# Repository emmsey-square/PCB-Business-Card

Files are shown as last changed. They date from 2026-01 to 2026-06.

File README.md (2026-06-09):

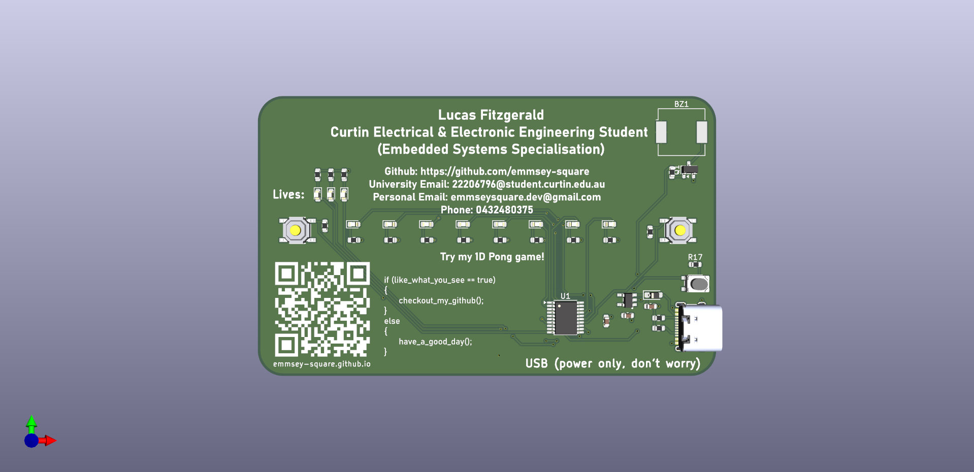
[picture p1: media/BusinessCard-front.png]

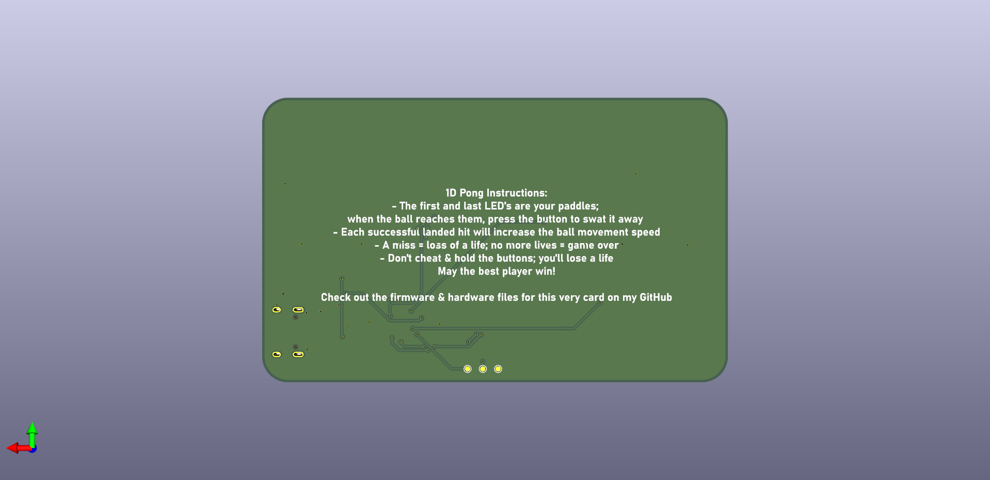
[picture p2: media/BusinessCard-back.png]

#   PCB Business Card- A Business Card to Help Me Stand Out

## Brief 
I've seen online heaps of people in the hobbyist/engineering field design their own business cards/badges to  give out to people, and I wnated to make one of my own to help me stand out among my peers.

My spin on the PCB business card is a simple 1D Pong game; there's a string of LED's between two pushbutton switches, with one LED lighting up at a time and moving along the string in alternating directions. When the LED reaches the end of the string, the player must press the button on that side to 'swat' it away, otherwise they will lose 1 of their 3 lives. Each successful swat increases the speed of the LED movement, until eventually it's impossible to win. Additionally, holding the buttons the whole time (AKA cheating) results in a loss of a life. Losing all lives results in game over. 
## Design Choices 
- Utilising a CH32V003 for my main mcu, as it is a cheap 32-bit RISCV chip with plenty of peripherals and IO for a business card. I have an interest in the RISCV ISA, and there's a huge open source community around this chip mainly thanks to cnlohr and his [ch32fun SDK](https://github.com/cnlohr/ch32fun) 
- USB-C port port mainstream compatibility, although people will be understandably hesitant to plug this into things
- Onboard passive buzzer for sound effects (work in progress)

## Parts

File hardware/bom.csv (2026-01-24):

Id | Designator | Footprint | Quantity | Designation | Supplier and ref
1 | J1 | USB-C_16 | 1 | USB_C_Receptacle
2 | R13,R8,R10,R9,R5,R7,R11,R12,R15,R14,R6 | R_0603_1608Metric | 11 | R
3 | R3,R4 | R_0603_1608Metric | 2 | 5.1k
4 | Q1 | SOT-23 | 1 | BC847
5 | D5,D4,D1,D3,D12,D7,D2,D8,D11,D10,D6 | LED_0603_1608Metric | 11 | LED
6 | U1 | TSSOP-20_4.4x6.5mm_P0.65mm | 1 | CH32V003FxPx
7 | BZ1 | Buzzer_CUI_CPT-9019S-SMT | 1 | Buzzer
8 | R17,R1,R2 | R_0603_1608Metric | 3 | 10k
9 | SW3 | Push_SMD_4.2x3.2mm | 1 | SMD_4.2x3.2mm_h2.5mm
10 | SW2,SW1 | Push_SMD_5.2x5.2mm_h1.9mm | 2 | SMD_5.2x5.2mm_h1.9mm
11 | C3 | C_0603_1608Metric | 1 | 10u
12 | D9 | D_SOD-323_HandSoldering | 1 | 1N5819WS
13 | R16 | R_0603_1608Metric | 1 | R
14 | C1 | C_0603_1608Metric | 1 | 0.1u
15 | U2 | SOT23-5 | 1 | RT9080-3.3
16 | C2 | C_0603_1608Metric | 1 | 1u
17 | TP3 | TestPoint_Pad_D1.0mm | 1 | GND
18 | TP1 | TestPoint_Pad_D1.0mm | 1 | SWIO
19 | TP2 | TestPoint_Pad_D1.0mm | 1 | 3.3V

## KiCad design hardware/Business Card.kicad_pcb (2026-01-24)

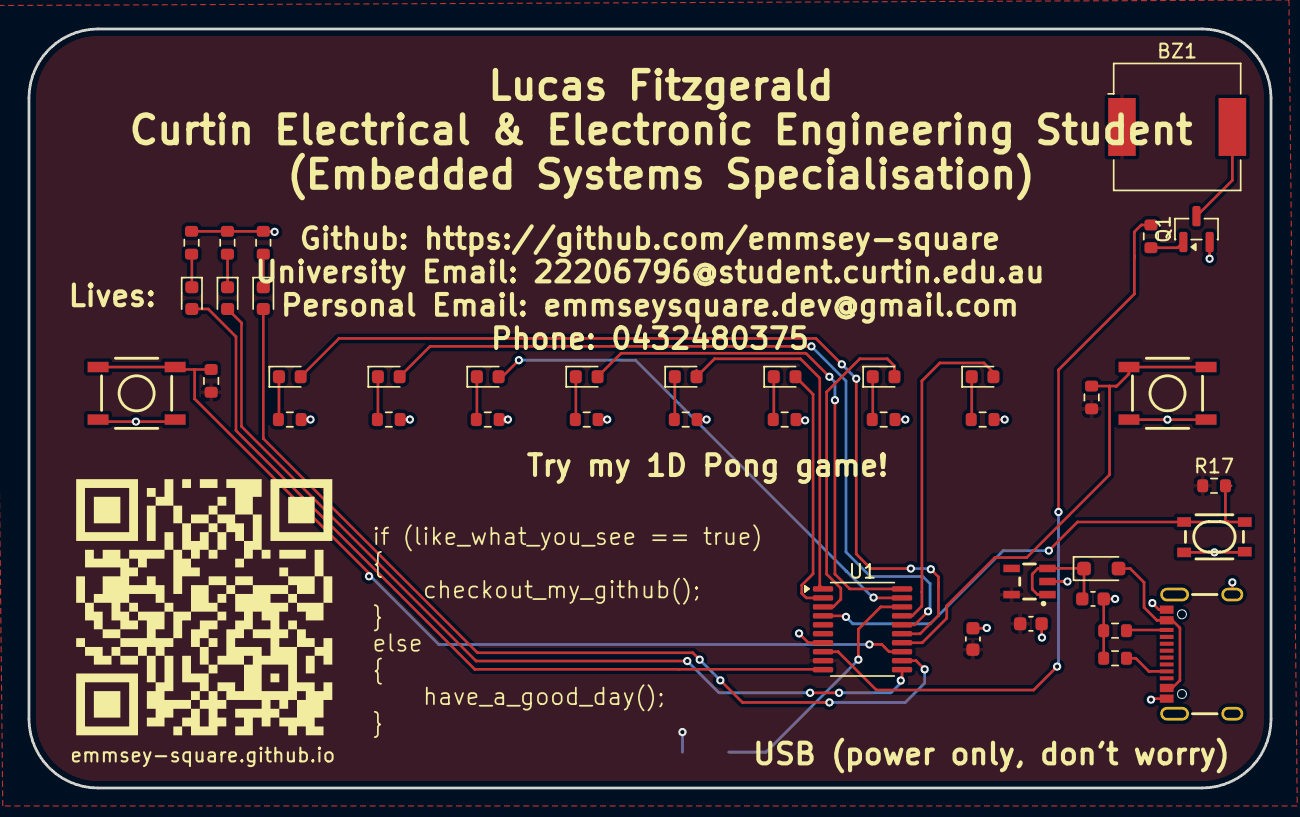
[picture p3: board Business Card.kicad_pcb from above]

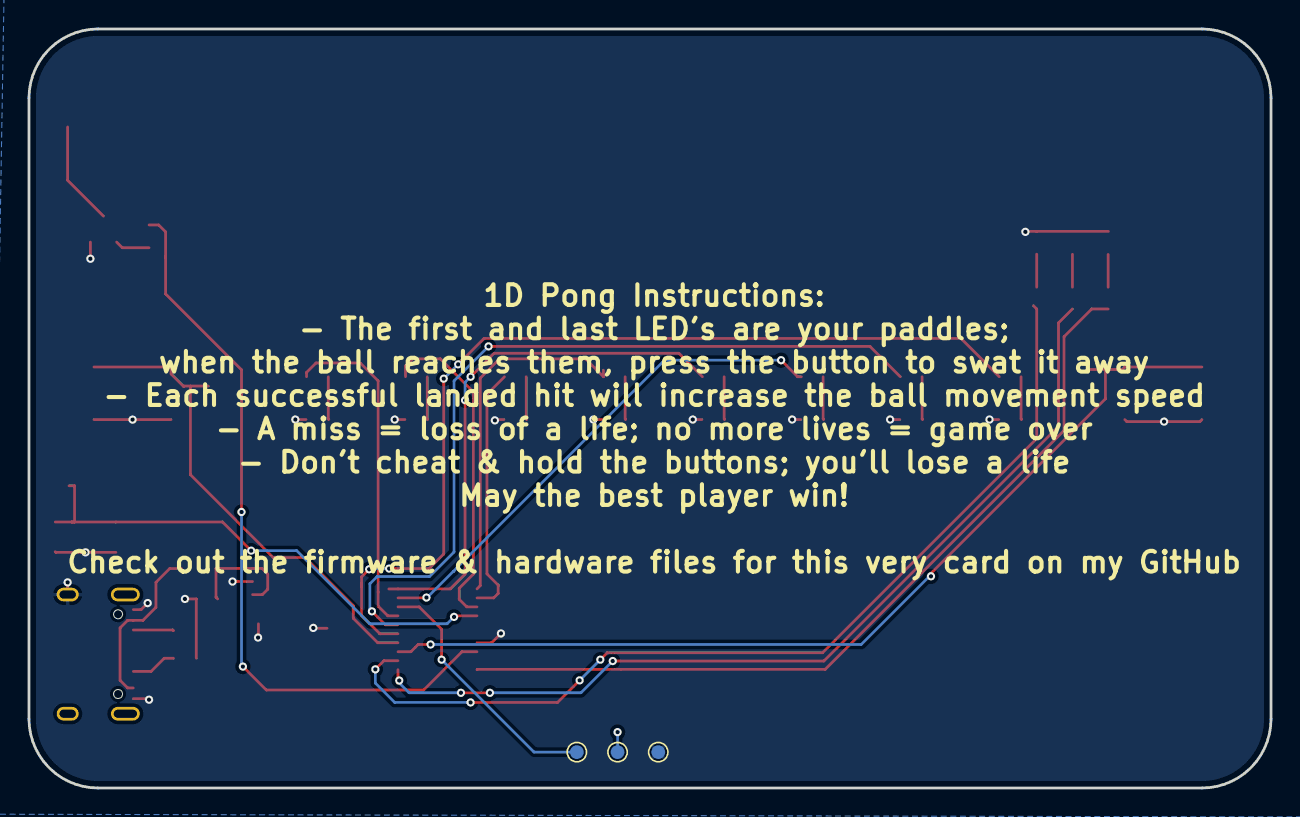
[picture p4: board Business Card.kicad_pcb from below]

Board: 2 copper layers, 90.0 x 55.0 mm, 43 parts (3 on the bottom side), 35 nets.

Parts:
BZ1: Buzzer; Buzzer_CUI_CPT-9019S-SMT
C1: 0.1u; C_0603_1608Metric
C2: 1u; C_0603_1608Metric
C3: 10u; C_0603_1608Metric
D1, D2, D3, D4, D5, D6, D7, D8, D10, D11, D12: LED; LED_0603_1608Metric
D9: 1N5819WS; D_SOD-323_HandSoldering
J1: USB_C_Receptacle; USB-C_16
Q1: BC847; SOT-23
R1, R2, R17: 10k; R_0603_1608Metric
R3, R4: 5.1k; R_0603_1608Metric
R5, R6, R7, R8, R9, R10, R11, R12, R13, R14, R15, R16: R; R_0603_1608Metric
SW1, SW2: SMD_5.2x5.2mm_h1.9mm; Push_SMD_5.2x5.2mm_h1.9mm
SW3: SMD_4.2x3.2mm_h2.5mm; Push_SMD_4.2x3.2mm
TP1: SWIO; TestPoint_Pad_D1.0mm
TP2: 3.3V; TestPoint_Pad_D1.0mm
TP3: GND; TestPoint_Pad_D1.0mm
U1: CH32V003FxPx; TSSOP-20_4.4x6.5mm_P0.65mm
U2: RT9080-3.3; SOT23-5

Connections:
+3.3V: BZ1.1 (+), C1.1, C3.1, R1.1, R2.1, R17.1, TP2.1, U1.9 (VDD), U2.5 (VOUT)
/BZR: R16.1, U1.8 (PD0)
/D0: D1.2 (A), U1.15 (PC5)
/D1: D2.2 (A), U1.16 (PC6)
/D2: D3.2 (A), U1.19 (PD2)
/D3: D4.2 (A), U1.20 (PD3)
/D4: D5.2 (A), U1.1 (PD4)
/D5: D6.2 (A), U1.2 (PD5)
/D6: D7.2 (A), U1.3 (PD6)
/D7: D8.2 (A), U1.17 (PC7)
/D10: D10.2 (A), U1.10 (PC0)
/D11: D11.2 (A), U1.11 (PC1)
/D12: D12.2 (A), U1.12 (PC2)
/NRST: R17.2, SW3.1, U1.4 (PD7)
/SW1: R1.2, SW1.1, U1.13 (PC3)
/SW2: R2.2, SW2.1, U1.14 (PC4)
/SWIO: TP1.1, U1.18 (PD1)
GND: C1.2, C2.2, C3.2, J1.GND, J1.S (SHIELD), Q1.2 (E), R3.2, R4.2, R5.2, R6.2, R7.2, R8.2, R9.2, R10.2, R11.2, R12.2, R13.2, R14.2, R15.2, SW1.2, SW2.2, SW3.2, TP3.1, U1.7 (VSS), U2.2 (GND)
unnamed: BZ1.2 (-), Q1.3 (C)
unnamed: D1.1 (K), R5.1
unnamed: D2.1 (K), R6.1
unnamed: D3.1 (K), R7.1
unnamed: D4.1 (K), R8.1
unnamed: D5.1 (K), R9.1
unnamed: D6.1 (K), R10.1
unnamed: D7.1 (K), R11.1
unnamed: D8.1 (K), R12.1
unnamed: D9.2 (A), J1.VBUS
unnamed: C2.1, D9.1 (K), U2.1 (VIN), U2.3 (EN)
unnamed: D10.1 (K), R13.1
unnamed: D11.1 (K), R14.1
unnamed: D12.1 (K), R15.1
unnamed: J1.A5 (CC1), R3.1
unnamed: J1.B5 (CC2), R4.1
unnamed: Q1.1 (B), R16.2

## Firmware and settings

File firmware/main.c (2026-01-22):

#include "ch32fun.h"
#include "funconfig.h"

#define SW1 PC3
#define SW2 PC4

uint8_t ledStrip[8] = {PC5, PC6, PD2, PD3, PD4, PD5, PD6, PC7};
uint8_t lifeLeds[3] = {PC0, PC1, PC2};

uint8_t lives = 4;	
uint32_t interval;
uint32_t pos = 0;
uint32_t prevLedTime, prevSwitchTime;
uint8_t sw1_state, sw2_state;
uint8_t started = 0;

inline uint32_t millis(void)
{
	return SysTick->CNT;
}


void clearLeds(void)
{
	for (uint8_t i = 0; i < 8; i++)
	{
		funDigitalWrite(ledStrip[i], FUN_HIGH);
	}
}


uint32_t moveLeds(uint32_t* interval)
{
	static uint32_t pos = 0, dir  = 1;

	if (lives == 0)
	{
		clearLeds();
	}
	else
	{
		if ((millis() - prevLedTime) >= *interval)
		{
			prevLedTime += *interval;
			
			clearLeds();

			if (dir)
				pos++;
			else 
				pos--;


			if (pos >= 7)
				dir = 0;
			else if (pos <= 0)
				dir = 1;
		}

		funDigitalWrite(ledStrip[pos], FUN_LOW);
	}

	return pos;
}

void loseLife(void)
{
	Delay_Ms(500);
	lives--;
}

void increaseSpeed(void)
{
	Delay_Ms(50);
	interval -= Ticks_from_Ms(5);
}

void gameOver(void)
{
	clearLeds();
	lives = 0;
}

void showLives(void)
{
	for (uint8_t i = 0; i < 3; i++)
		funDigitalWrite(lifeLeds[i], FUN_HIGH);
	
	switch (lives)
	{
		case 0:
			for (uint8_t i = 0; i < 3; i++)
				funDigitalWrite(lifeLeds[i], FUN_HIGH);
			break;
		case 1:
			funDigitalWrite(lifeLeds[0], FUN_LOW);
			break;
		case 2:
			for (uint8_t i = 0; i < 2; i++)
				funDigitalWrite(lifeLeds[i], FUN_LOW);
			break;
		case 3:
			for (uint8_t i = 0; i < 3; i++)
				funDigitalWrite(lifeLeds[i], FUN_LOW);
			break;
		default:
			gameOver();
			break;
	}
}


int main(void)
{
	SystemInit();
	funGpioInitAll();
	
	funPinMode(SW1, GPIO_Speed_In | GPIO_CNF_IN_FLOATING);
	funPinMode(SW2, GPIO_Speed_In | GPIO_CNF_IN_FLOATING);
	
	interval = Ticks_from_Ms(500);	

	prevLedTime = millis();

	for (uint8_t i = 0; i < 8; i++)
	{
		funPinMode(ledStrip[i], GPIO_Speed_10MHz | GPIO_CNF_OUT_PP);
	}
	
	for (uint8_t i = 0; i < 3; i++)
	{
		funPinMode(lifeLeds[i], GPIO_Speed_10MHz | GPIO_CNF_OUT_PP);
	}

	clearLeds();

	for (;;)
	{			
		sw1_state = funDigitalRead(SW1);
		sw2_state = funDigitalRead(SW2);

		pos = moveLeds(&interval);
		
		if ( (!sw1_state && (pos == 0)) || (!sw2_state && (pos == 7)) )
		{
			increaseSpeed();
		}
		else if ( ((pos == 0) && (sw1_state == 1)) || ((pos == 7) && (sw2_state == 1)) )	
		{
			loseLife();
		}
		else if (!sw1_state && !sw2_state)
		{
			loseLife();
		}
		
		showLives();
	}

	return 0;
}

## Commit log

2026-01-19 updated main.c, implemented lives functionality mostly, working out bugs in determing if game has started or not
    [main.c]
2026-01-22 fixed simulatneous button press bug, losing all lives results in game over
    [main.c]
2026-01-24 Added kicad hardware files, gerbers & bom
    [Business Card.kicad_pcb, Business Card.kicad_sch, bom.csv]
